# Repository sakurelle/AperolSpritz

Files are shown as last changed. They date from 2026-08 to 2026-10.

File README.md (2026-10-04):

# AperolSpritz — измеритель длины игл на ESP32-C3

AperolSpritz — автоматический измеритель длины игл на базе ESP32-C3 и шагового двигателя с драйвером TMC2209.

Устройство поддерживает ручное и автоматическое измерение, ручную и автоматическую калибровку, Web UI, сохранение настроек в NVS, сервисную калибровку перемещения в миллиметрах, аварийный STOP, световую и звуковую индикацию.

---

# 1. Как пользоваться

## 1.1. Перед первым использованием

Перед началом работы:

1. Убедитесь, что каретка свободно перемещается и механически не упирается в край хода.
2. Убедитесь, что `CONTACT` в исходном положении разомкнут.
3. Убедитесь, что кнопка `STOP` не нажата.
4. Проверьте работу оптического датчика иглы:
   - игла установлена → `NEEDLE = LOW`;
   - игла отсутствует → `NEEDLE = HIGH`.
5. Подключитесь к Web UI.
6. Проверьте настройки оператора:
   - номинальную длину;
   - допуск;
   - длину ручного калибра;
   - длину автокалибра;
   - расстояние отъезда;
   - направление движения (`Инвертировать DIR`).
7. При необходимости сначала откалибруйте масштаб перемещения в сервисном разделе.
8. Выполните калибровку устройства.

> После изменения `mm_per_step`, длины ручного/автоматического калибра или направления DIR текущая метрологическая калибровка становится недействительной. После таких изменений нужно выполнить калибровку заново.

---

# 2. Web-интерфейс

После подключения ESP32-C3 к сети откройте в браузере (IP-адрес указан на шаговом двигателе):

```text
http://<IP-адрес устройства>/
```

Интерфейс показывает:

- последнее измерение;
- отклонение от номинала;
- номинальную длину;
- допуск;
- цветовую оценку результата;
- состояние иглы;
- состояние CONTACT;
- состояние STOP;
- текущую ошибку;
- режим Wi-Fi и IP;
- текущую фазу FSM;
- состояние автоматического режима;
- тип и опорную длину последней калибровки;
- количество измерений после калибровки;
- сервисную калибровку перемещения.

### Цвет результата

В Web UI используется следующая индикация:

- **зелёный** — результат находится в допуске и не ближе 80% допуска к его границе;
- **жёлтый** — результат ещё в допуске, но отклонение достигло не менее 80% допуска;
- **красный** — результат вышел за допуск;
- **серый** — измерения ещё не было.

---

# 3. Ручной режим

## 3.1. Ручная калибровка

Ручная калибровка задаёт точку отсчёта для последующих измерений.

Перед калибровкой:

- `STOP` должен быть неактивен;
- `CONTACT` должен быть свободен;
- автоматический режим должен быть выключен;
- в настройках должна быть указана фактическая длина ручного калибра.

Калибровку можно запустить:

- кнопкой `CALIBRATE`;
- кнопкой **Калибровать** в Web UI.

Оптический датчик `NEEDLE` при ручной калибровке не используется.

Последовательность:

```text
быстрый подход
    ↓
CONTACT
    ↓
отъезд
    ↓
медленный точный подход
    ↓
CONTACT
    ↓
финальный отъезд
    ↓
готово
```

В качестве калибровочной координаты сохраняется только точка второго, медленного касания.

После успешной калибровки устройство запоминает:

- координату точного CONTACT;
- длину использованного калибра;
- тип калибровки `MANUAL`.

---

## 3.2. Ручное измерение

Перед измерением должны выполняться условия:

- устройство откалибровано;
- игла обнаружена оптическим датчиком;
- `CONTACT` в исходном положении свободен;
- `STOP` неактивен.

Измерение можно запустить:

- кнопкой `MEASURE`;
- кнопкой **Измерить** в Web UI.

Алгоритм такой же двухпроходный:

```text
быстрый подход
    ↓
CONTACT
    ↓
отъезд
    ↓
медленный точный подход
    ↓
CONTACT
    ↓
финальный отъезд
    ↓
результат
```

Итоговая длина определяется по координате второго касания.

После точного касания в `MEASURE_FINE` результат уже зафиксирован, поэтому во время финального отъезда иглу можно снимать.

---

# 4. Автоматический режим

Автоматический режим предназначен для циклической работы без запуска каждого измерения вручную.

Включается кнопкой:

```text
Авто: ВКЛ
```

в Web UI.

Автоматический цикл:

```text
ожидание иглы
    ↓
игла установлена
    ↓
автоматическое измерение
    ↓
ожидание снятия иглы
    ↓
игла снята
    ↓
автокалибровка
    ↓
возврат каретки в загрузочную позицию
    ↓
ожидание освобождения оптического датчика
    ↓
ожидание следующей иглы
```

В автоматическом режиме оптический датчик используется для определения установки и снятия иглы.

Во время самой автокалибровки и возврата каретки ложные перекрытия оптического датчика не должны запускать новое измерение. Новая игла принимается только после того, как датчик сначала устойчиво подтвердил свободное состояние.

Автоматический режим выключается при:

- STOP;
- ошибке;
- ручной команде остановки AUTO.

После перезагрузки автоматический режим не считается включённым.

---

# 5. Световая и звуковая индикация

## Буззер (Динамик)

Текущая прошивка использует активный буззер на `GPIO8`.

Сигналы:

- короткий писк — началось измерение;
- короткий писк — началась калибровка;
- более длинный писк — операция успешно завершена и устройство снова перешло в ожидание;
- три коротких прерывистых сигнала — возникла ошибка.

Сервисное перемещение не использует обычные сигналы измерения/калибровки.

Параметры звука находятся в:

```text
main/config/indicator_config.hpp
```

Основные параметры:

```cpp
BUZZER_START_MS
BUZZER_SUCCESS_MS
BUZZER_ERROR_ON_MS
BUZZER_ERROR_OFF_MS
BUZZER_ERROR_COUNT
BUZZER_INVERTED
```

## Светодиод

Статусный светодиод подключён к `GPIO9`.

Логика:

| Состояние | LED |
|---|---|
| Ожидание | выключен |
| Измерение | горит |
| Калибровка | горит |
| Возврат / JOG / сервисное движение | горит |
| ERROR | мигает |
| STOP | выключен |

В текущей конфигурации:

```cpp
STATUS_LED_INVERTED = true;
```

То есть логическое включение LED соответствует низкому уровню на GPIO9.

---

# 6. STOP и ошибки

## STOP

`STOP` имеет максимальный приоритет.

При его срабатывании:

- STEP немедленно прекращается;
- TMC2209 отключается через `EN`;
- автоматический режим выключается;
- текущий звук прекращается;
- FSM переходит в `STOPPED`.

После физического освобождения кнопки STOP нужно выполнить:

```text
Сброс STOP
```

в Web UI.

## Ошибки

При ошибке:

- двигатель останавливается;
- автоматический режим выключается;
- статусный LED начинает мигать;
- буззер один раз воспроизводит прерывистый аварийный сигнал;
- устройство остаётся в `ERROR`.

После устранения причины нажмите:

```text
Сброс ошибки
```

Основные ошибки:

| Ошибка | Значение |
|---|---|
| `NEEDLE_NOT_FOUND` | игла не обнаружена или исчезла во время измерения |
| `CONTACT_ALREADY_ACTIVE` | CONTACT уже замкнут до начала операции |
| `CONTACT_RELEASE_TIMEOUT` | после отъезда CONTACT не освободился |
| `MEASUREMENT_TIMEOUT` | превышено максимальное время измерения |
| `CALIBRATION_TIMEOUT` | превышено максимальное время калибровки |
| `MAX_STEPS_REACHED` | достигнут лимит перемещения |
| `NOT_CALIBRATED` | попытка измерения без действующей калибровки |
| `STOP_ACTIVE` | активен STOP |
| `INVALID_CONFIG` | некорректные параметры |
| `INTERNAL_ERROR` | внутренняя ошибка или остановка движения |

---

# 7. Ручной отъезд LEFT / JOG

Кнопка `LEFT` используется для ручного движения каретки от измерительного контакта.

Пока кнопка удерживается:

```text
каретка движется влево / от CONTACT
```

После отпускания движение прекращается.

JOG доступен только вне автоматического режима.

Активный CONTACT не запрещает движение от него.

---

# 8. Калибровка перемещения и mm_per_step

В нижней части Web UI расположен сервисный раздел:

```text
Калибровка перемещения
```

Он предназначен для настройки коэффициента:

```text
mm_per_step
```

то есть фактического линейного перемещения каретки на один импульс STEP.

Сервисное движение доступно только когда:

- FSM находится в `IDLE`;
- AUTO выключен;
- STOP неактивен;
- нет ошибки;
- мотор не выполняет другое движение.

Максимальная команда:

```text
±150 мм
```

Знак задаёт направление:

```text
-100 мм → влево
+100 мм → вправо
```

Если CONTACT уже активен, разрешается только движение от контакта.

## Порядок калибровки

1. Введите известное перемещение, например:

```text
-100.000 мм
```

2. Нажмите **Переместить**.
3. Измерьте реальный ход каретки.
4. Введите фактическое перемещение положительным числом, например:

```text
99.720 мм
```

5. Нажмите **Рассчитать**.

Web UI вычислит:

```text
ошибку в мм
ошибку в %
новый mm_per_step
новое количество шагов на мм
```

Используется формула:

```text
new_mm_per_step =
    old_mm_per_step × actual_distance / commanded_distance
```

6. Нажмите **Применить коэффициент**.
7. Подтвердите изменение.
8. Повторите тестовое перемещение.
9. После настройки обязательно выполните новую калибровку измерителя.

`mm_per_step` сохраняется в NVS и используется всеми преобразованиями миллиметров в шаги и обратно.

> Устройство не имеет абсолютного HOME. Перед сервисным движением оператор обязан убедиться, что каретке хватает свободного механического хода.

---

# 9. Настройки оператора

Через Web UI изменяются:

| Параметр | Назначение |
|---|---|
| Номинальная длина | размер, относительно которого рассчитывается отклонение |
| Допуск | допустимое абсолютное отклонение |
| Длина ручного калибра | известная длина при ручной калибровке |
| Длина автокалибра | известная длина встроенного автоматического калибра |
| Расстояние отъезда | ход каретки после касания CONTACT |
| Инвертировать DIR | меняет физическое направление подхода |

`mm_per_step` не редактируется в обычном блоке настроек. Он изменяется только через сервисную калибровку перемещения.

---

# 10. Как считается длина

Устройство хранит знаковую программную координату:

```text
position_steps
```

Она изменяется на каждом реально сформированном импульсе STEP.

Во время калибровки запоминается координата:

```text
calibration_contact_position_steps
```

Во время измерения:

```text
measurement_contact_position_steps
```

Расчёт основан на разности координат:

```text
L =
    calibration_reference_length_mm
    + direction_sign
    × (calibration_position - measurement_position)
    × mm_per_step
```

Направление автоматически учитывает параметр `measure_dir_inverted`.

`position_steps` является относительной программной координатой.

Она остаётся корректной только пока:

- двигатель не пропускает шаги;
- каретка не перемещается вручную при отключённом приводе;
- механика не проскальзывает.

Абсолютного HOME-датчика в текущей конструкции нет.

---

# 11. Алгоритм CONTACT

CONTACT — отдельный измерительный вход.

Логика:

```text
HIGH = свободен
LOW  = контакт замкнут
```

При первом переходе CONTACT в LOW генерация STEP останавливается максимально быстро.

После этого контроллер подтверждает уровень с коротким debounce. Если импульс оказался дребезгом и CONTACT снова стал HIGH, текущее движение продолжается без сброса программной координаты.

В итоговую калибровку и измерение используется только точка второго, медленного касания.

---

# 12. Подключение электроники

Текущая прошивка рассчитана на ESP32-C3 и драйвер TMC2209 в режиме STEP/DIR/EN.

UART-интерфейс TMC2209 прошивкой не используется.

## GPIO

| GPIO | Сигнал | Тип | Логика |
|---:|---|---|---|
| 0 | `STOP` | вход | LOW — аварийная остановка |
| 1 | `LEFT` | вход | LOW — ручной отъезд |
| 2 | `CALIBRATE` | вход | LOW — ручная калибровка |
| 3 | `CONTACT` | вход | LOW — контакт замкнут |
| 4 | `NEEDLE` | вход | LOW — игла есть, HIGH — иглы нет |
| 5 | `DIR` | выход | направление TMC2209 |
| 6 | `STEP` | выход | импульсы TMC2209 |
| 7 | `EN` | выход | LOW — драйвер включён |
| 8 | `BUZZER` | выход | звуковая индикация |
| 9 | `STATUS_LED` | выход | статусный LED, по умолчанию active-low |
| 10 | `MEASURE` | вход | LOW — ручное измерение |

### Кнопки

`STOP`, `LEFT`, `CALIBRATE`, `MEASURE` и `CONTACT` настроены как active-low входы с внутренней подтяжкой вверх.

Для обычной кнопки:

```text
GPIO ─── кнопка ─── GND
```

### Оптический датчик NEEDLE

GPIO4 не использует внутреннюю подтяжку.

Датчик должен сам формировать цифровой уровень:

```text
датчик OUT → GPIO4
датчик GND → общий GND
```

Логика текущей прошивки:

```text
LOW  = игла обнаружена
HIGH = игла отсутствует
```

Выход датчика должен быть совместим с логическими уровнями ESP32-C3.

### CONTACT

CONTACT электрически независим от оптического датчика.

Контакт должен замыкать GPIO3 на GND:

```text
GPIO3 ─── CONTACT ─── GND
```

### TMC2209

Минимальные управляющие сигналы:

```text
GPIO5 → DIR
GPIO6 → STEP
GPIO7 → EN
GND   → GND драйвера
```

`EN` активен низким уровнем.

Питание двигателя, ток драйвера и микрошаг должны быть настроены в соответствии с конкретным двигателем, драйвером и механикой. Эти параметры прошивка не конфигурирует.

### Буззер

Текущая прошивка:

```text
GPIO8 → BUZZER
```

`BUZZER_INVERTED = false`.

Если используется активный буззер в текущей прототипной схеме:

```text
GPIO8 → (+) buzzer
GND   → (-) buzzer
```

Если конкретный буззер требует ток выше допустимого для GPIO, его нужно подключать через транзисторный ключ.

### Статусный LED

Текущая прошивка использует active-low LED:

```text
3.3 V
  │
резистор
  │
 LED
  │
GPIO9
```

По умолчанию:

```text
GPIO9 LOW  → LED ON
GPIO9 HIGH → LED OFF
```

---

# 13. Важное замечание по GPIO2, GPIO8 и GPIO9

GPIO2, GPIO8 и GPIO9 у ESP32-C3 являются strapping-пинами и считываются во время reset.

В текущей распиновке на них находятся:

```text
GPIO2 → CALIBRATE
GPIO8 → BUZZER
GPIO9 → STATUS_LED
```

Поэтому внешняя схема не должна принудительно формировать неправильные уровни на этих выводах во время загрузки.

В частности:

- не удерживайте `CALIBRATE` нажатой при включении/сбросе;
- не допускайте сильной внешней подтяжки GPIO9 к GND во время reset;
- не устанавливайте большую ёмкость на GPIO9;
- при проблемах с загрузкой сначала отключите внешние цепи GPIO2/GPIO8/GPIO9 и проверьте старт ESP32-C3.

---

# 14. Wi-Fi

Прошивка поддерживает:

- WPA2-PSK;
- WPA2-Enterprise / PEAP;
- автоматический fallback Access Point.

## Настройка STA

Скопируйте:

```text
secrets.example.txt
```

в:

```text
secrets.txt
```

и укажите реальные параметры сети.

> `secrets.txt` содержит пароль. Не добавляйте этот файл в Git!!!

### WPA2-PSK

```text
WIFI_AUTH=psk
WIFI_SSID=YOUR_SSID
WIFI_PASSWORD=YOUR_PASSWORD
```

### WPA2-Enterprise / PEAP

```text
WIFI_AUTH=enterprise
WIFI_SSID=YOUR_SSID
WIFI_IDENTITY=YOUR_IDENTITY
WIFI_USERNAME=YOUR_USERNAME
WIFI_PASSWORD=YOUR_PASSWORD
```

Во время сборки `secrets.txt` преобразуется CMake в заголовочный файл внутри build directory.

Пароль не отдаётся через Web UI или REST API.

## Fallback AP

Если credentials отсутствуют, некорректны или устройство не подключилось к STA за время ожидания, запускается точка доступа:

```text
SSID:     NeedleMeter
Password: NeedleMeter2026
IP:       192.168.4.1
```

После подключения откройте:

```text
http://192.168.4.1/
```

Если STA-соединение было установлено, но затем потеряно, прошивка пытается переподключиться.

Физические кнопки и измерительная FSM не зависят от доступности Wi-Fi.

---

# 15. Технические параметры движения

Основные compile-time параметры находятся в:

```text
main/config/motion_config.hpp
```

Текущие значения:

| Параметр | Значение |
|---|---:|
| Coarse speed | 1500 шаг/с |
| Fine speed | 500 шаг/с |
| Retract speed | 1500 шаг/с |
| Auto load speed | 4000 шаг/с |
| JOG speed | 4000 шаг/с |
| Service move speed | 4000 шаг/с |
| Acceleration | 4000 шаг/с² |
| Max retract | 20 мм |
| Max measurement move | 75 мм |
| Max calibration move | 75 мм |
| Max auto load move | 30 мм |
| Max service move | 150 мм |
| CONTACT debounce | 3 мс |
| NEEDLE debounce AUTO | 100 мс |
| STEP high | 4 мкс |
| AUTO load position | 182 мм |

Начальное значение масштаба:

```text
DEFAULT_MM_PER_STEP = 0.0003127
```

Рабочий `mm_per_step` хранится в `DeviceConfig` и NVS.

---

# 16. Сборка прошивки

Проект использует:

```text
PlatformIO
ESP-IDF
ESP32-C3 DevKitM-1
```

Конфигурация находится в:

```text
platformio.ini
```

Сборка:

```powershell
pio run
```

Прошивка:

```powershell
pio run -t upload
```

Монитор:

```powershell
pio device monitor
```

Скорость монитора:

```text
115200 baud
```

Консоль ESP-IDF настроена через USB Serial/JTAG.

---

# 17. REST API

Web UI использует тот же REST API.

| Метод | Endpoint | Назначение |
|---|---|---|
| GET | `/api/status` | текущее состояние |
| GET | `/api/config` | текущая конфигурация |
| POST | `/api/config` | сохранить настройки оператора |
| POST | `/api/measure` | начать измерение |
| POST | `/api/calibrate` | начать ручную калибровку |
| POST | `/api/auto/start` | включить AUTO |
| POST | `/api/auto/stop` | выключить AUTO |
| POST | `/api/stop` | программный STOP |
| POST | `/api/reset-stop` | сбросить STOP |
| POST | `/api/reset-error` | сбросить ERROR |
| POST | `/api/factory-reset` | сбросить NVS к значениям по умолчанию |
| POST | `/api/service-move` | сервисное перемещение в мм |
| POST | `/api/service/mm-per-step` | сохранить новый коэффициент mm/step |

Пример сервисного перемещения:

```json
{
  "distance_mm": -100.0
}
```

---

# 18. Хранение конфигурации

Настройки и статистика сохраняются в NVS namespace:

```text
needle_meter
```

В NVS сохраняются, в частности:

- настройки оператора;
- `mm_per_step`;
- последняя действующая калибровка;
- тип калибровки;
- координата калибровочного CONTACT;
- последнее измерение;
- счётчики измерений и калибровок.

Текущая версия структуры конфигурации:

```text
CONFIG_VERSION = 5
```

При обновлении с версии 4 настройки оператора мигрируют в v5, а новый `mm_per_step` получает значение по умолчанию.

---

# 19. Структура проекта

```text
AperolSpritz/
├── hardware/                     # аппаратная/механическая часть проекта
├── main/
│   ├── app_main.cpp              # запуск подсистем
│   ├── config/
│   │   ├── pins.hpp              # назначение GPIO
│   │   ├── motion_config.hpp     # скорости и ограничения движения
│   │   ├── indicator_config.hpp
│   │   ├── device_config.*
│   │   └── config_storage.*
│   ├── gpio/                     # кнопки и датчики
│   ├── motor/                    # STEP/DIR/EN и GPTimer
│   ├── indication/               # buzzer + status LED
│   ├── measurement/              # FSM измерения и калибровки
│   ├── wifi/                     # STA / WPA2 Enterprise / fallback AP
│   └── web/                      # Web UI и REST API
├── platformio.ini
├── sdkconfig.defaults
├── secrets.example.txt
└── README.md
```

---

# 20. Общая архитектура

```text
Кнопки / датчики
       │
       ▼
   GpioManager
       │
       ▼
MeasurementController
       │
       ├────────► IndicatorManager
       │             ├─ buzzer
       │             └─ status LED
       │
       ▼
  StepperMotor
       │
       ▼
STEP / DIR / EN
       │
       ▼
    TMC2209
```

Web UI работает через REST API:

```text
Browser
   │
   ▼
WebServer
   │
   ▼
очередь команд
   │
   ▼
MeasurementController
```

HTTP handler не управляет мотором напрямую.

STEP формируется аппаратным GPTimer, а логика измерения выполняется конечным автоматом в отдельной FreeRTOS-задаче.

---

# 21. Типичный порядок настройки нового устройства

```text
Сборка механики и электроники
        ↓
проверка направления движения
        ↓
проверка STOP / CONTACT / NEEDLE
        ↓
настройка Wi-Fi
        ↓
сервисное перемещение ±100 мм
        ↓
коррекция mm_per_step
        ↓
повторная проверка перемещения
        ↓
ввод точной длины калибра
        ↓
калибровка
        ↓
контрольные измерения известных игл
        ↓
работа в ручном или автоматическом режиме
```

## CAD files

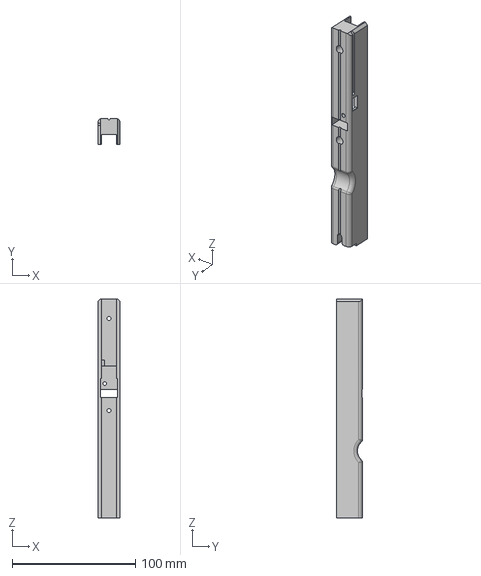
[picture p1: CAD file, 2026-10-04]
hardware/step/NeedleBase.stp
18.0 x 21.0 x 178.0 mm

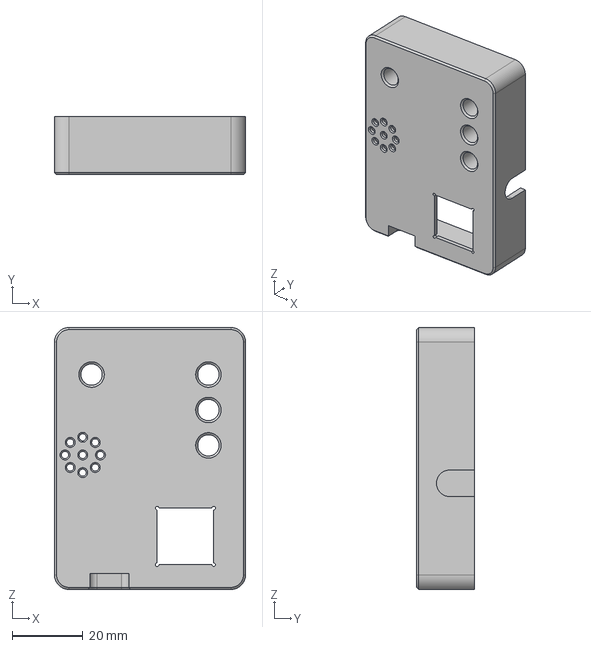
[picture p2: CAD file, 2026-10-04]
hardware/step/ControlHolderUp.stp
54.0 x 16.4 x 74.0 mm

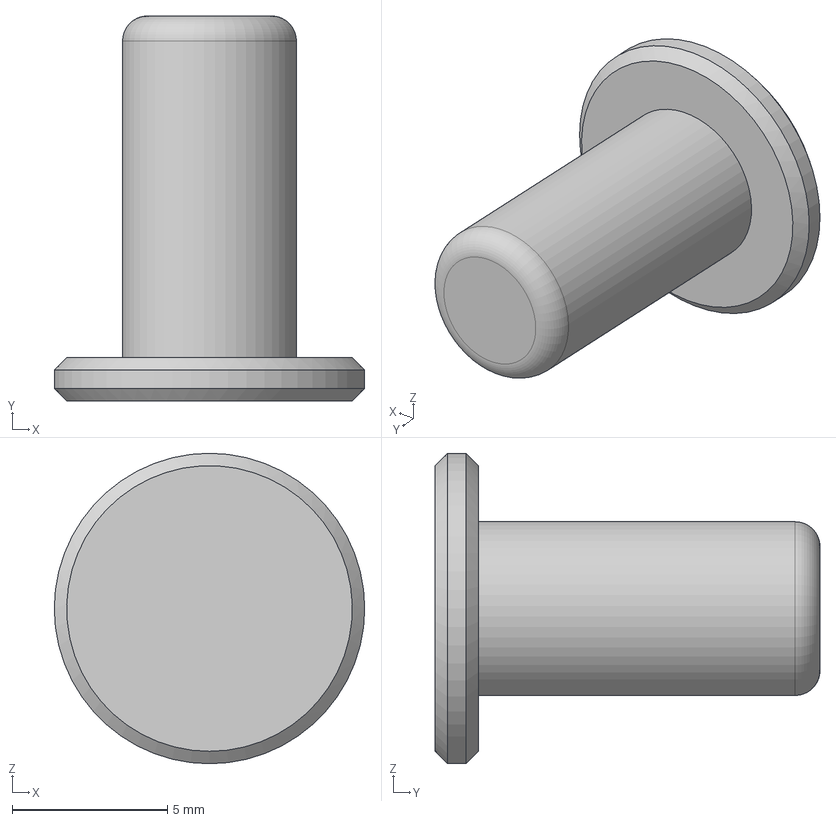
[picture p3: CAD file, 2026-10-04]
hardware/step/Button.stp
10.0 x 12.4 x 10.0 mm

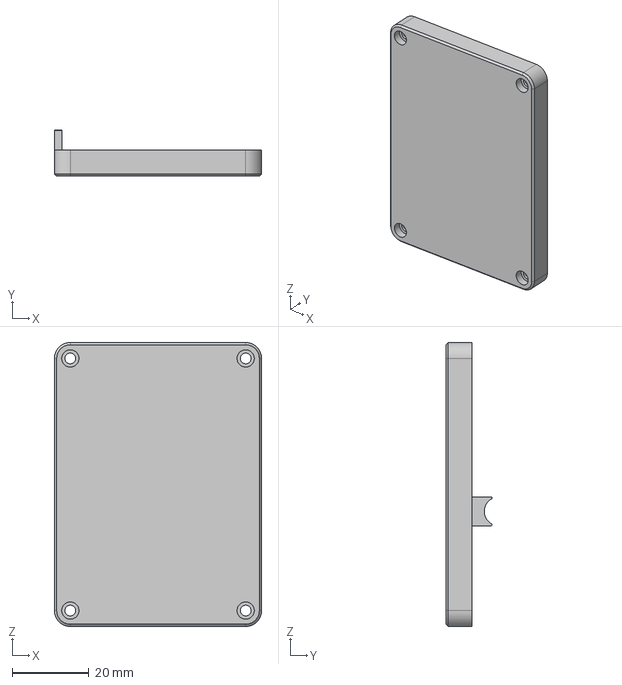
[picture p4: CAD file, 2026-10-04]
hardware/step/ControlHolderDown.stp
54.0 x 12.1 x 74.0 mm

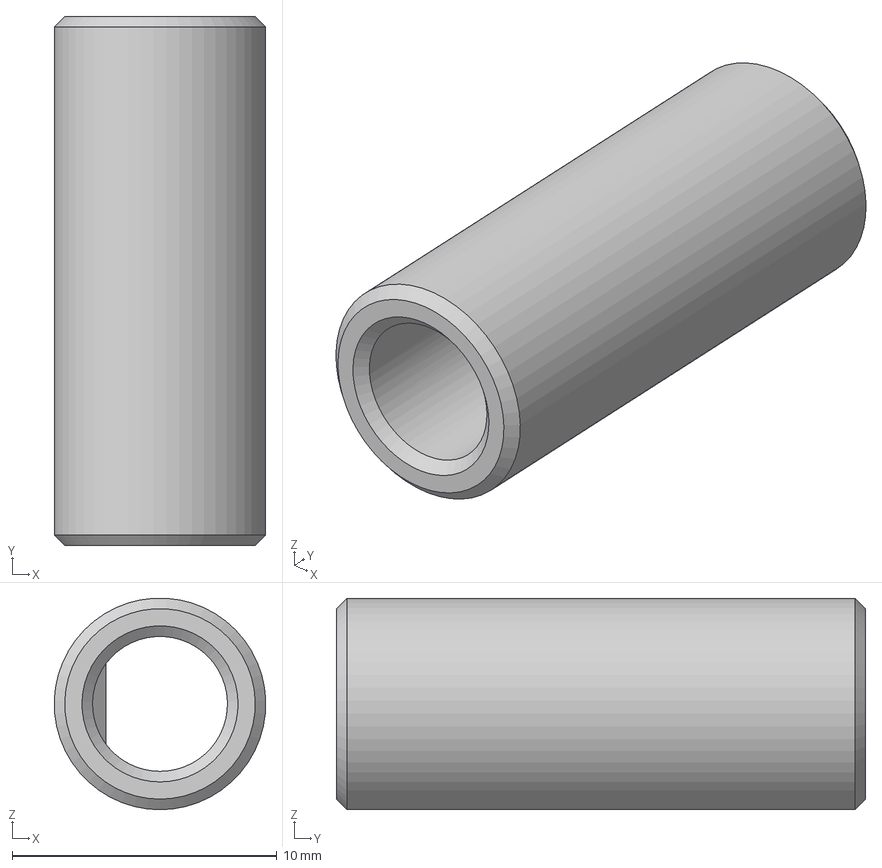
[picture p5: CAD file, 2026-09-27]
hardware/step/MotorWall.stp
8.00 x 20.0 x 7.99 mm

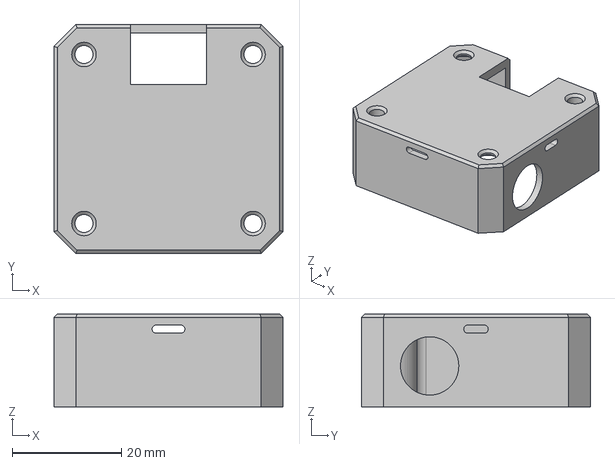
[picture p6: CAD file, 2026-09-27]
hardware/step/MotorWireBox.stp
42.0 x 42.0 x 17.0 mm

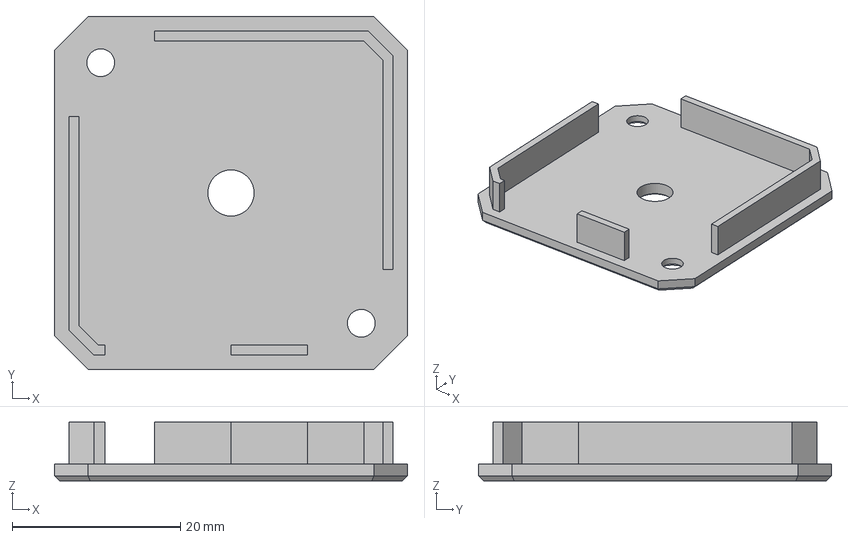
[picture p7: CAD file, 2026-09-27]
hardware/step/MotorWireRoof.stp
42.0 x 42.0 x 7.00 mm

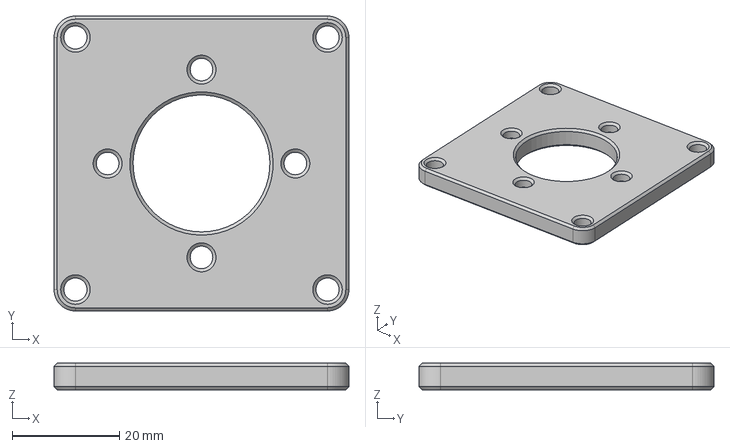
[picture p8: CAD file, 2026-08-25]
hardware/step/MotorBase.stp
55.0 x 55.0 x 5.00 mm

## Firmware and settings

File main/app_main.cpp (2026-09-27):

#include "driver/gpio.h"
#include "esp_log.h"
#include "config/pins.hpp"
#include "config/config_storage.hpp"
#include "gpio/gpio_manager.hpp"
#include "indication/indicator_manager.hpp"
#include "motor/stepper_motor.hpp"
#include "measurement/measurement_controller.hpp"
#include "wifi/wifi_manager.hpp"
#include "web/web_server.hpp"

static const char *TAG = "app";
// app_main returns after startup, so application services must not be stack objects.
static ConfigStorage storage;
static StepperMotor motor;
static GpioManager gpio;
static IndicatorManager indicator;
static MeasurementController controller;
static WifiManager wifi;
static WebServer web;

extern "C" void app_main(void) {
    // Put the driver in a safe electrical state before NVS, Wi-Fi, or any task can run.
    gpio_config_t safety{};
    safety.pin_bit_mask = (1ULL << STEP_PIN) | (1ULL << DIR_PIN) | (1ULL << EN_PIN);
    safety.mode = GPIO_MODE_OUTPUT;
    ESP_ERROR_CHECK(gpio_config(&safety));
    ESP_ERROR_CHECK(gpio_set_level(STEP_PIN, 0));
    ESP_ERROR_CHECK(gpio_set_level(DIR_PIN, 0));
    ESP_ERROR_CHECK(gpio_set_level(EN_PIN, 1)); // TMC2209 EN is active LOW
    if (indicator.init() != ESP_OK) { ESP_LOGE(TAG, "Indicator initialization failed"); return; }

    if (storage.init() != ESP_OK) { ESP_LOGE(TAG, "NVS initialization failed; motor remains disabled"); return; }
    DeviceConfig config; DeviceStats stats; bool defaults = false;
    if (storage.load(config, stats, defaults) != ESP_OK || !validate_config(config)) { ESP_LOGE(TAG, "Invalid NVS configuration; motor remains disabled"); return; }
    if (defaults) { ESP_LOGW(TAG, "Using factory defaults"); storage.save_config(config); storage.save_stats(stats); }

    if (motor.init() != ESP_OK) { ESP_LOGE(TAG, "Motor initialization failed"); return; }
    if (controller.init(&motor, &gpio, &storage, &indicator, config, stats) != ESP_OK) { ESP_LOGE(TAG, "GPIO/controller initialization failed"); motor.stop(); return; }
    if (controller.start_task() != ESP_OK) { ESP_LOGE(TAG, "Controller task initialization failed"); motor.stop(); return; }

    if (wifi.start() != ESP_OK) ESP_LOGE(TAG, "Wi-Fi unavailable; physical controls remain active");
    if (web.start(&controller, &wifi) != ESP_OK) ESP_LOGE(TAG, "HTTP server unavailable; physical controls remain active");
}

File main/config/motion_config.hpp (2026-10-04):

#pragma once

#include <cmath>
#include <limits>
#include <stdint.h>

// Machine-specific motion limits and speeds. The actual carriage scale lives
// in DeviceConfig so it can be calibrated and persisted in NVS.
namespace motion_config {
constexpr double DEFAULT_MM_PER_STEP = 0.0003127;
constexpr double MIN_MM_PER_STEP = 0.00001;
constexpr double MAX_MM_PER_STEP = 0.01;
constexpr uint32_t COARSE_SPEED_STEPS_S = 1500;
constexpr uint32_t FINE_SPEED_STEPS_S = 500;
constexpr uint32_t RETRACT_SPEED_STEPS_S = 1500;
constexpr uint32_t AUTO_LOAD_SPEED_STEPS_S = 4000;
constexpr uint32_t JOG_SPEED_STEPS_S = 4000;
constexpr uint32_t SERVICE_MOVE_SPEED_STEPS_S = 4000;
constexpr uint32_t ACCELERATION_STEPS_S2 = 4000;

constexpr double MAX_RETRACT_MM = 20.0;
constexpr double MAX_MEASUREMENT_MM = 75.0;
constexpr double MAX_CALIBRATION_MM = 75.0;
constexpr double MAX_AUTO_LOAD_MM = 30.0;
constexpr double MAX_SERVICE_MOVE_MM = 150.0;

// Returns zero for invalid, unrepresentable, or sub-step distances. All
// runtime mm/step conversions must go through these helpers.
inline uint32_t mm_to_steps(double mm, double mm_per_step) {
    const double distance = std::fabs(mm);
    if (!std::isfinite(distance) || !std::isfinite(mm_per_step) || mm_per_step <= 0.0) return 0;
    const double raw_steps = distance / mm_per_step;
    if (!std::isfinite(raw_steps) || raw_steps < 0.5 || raw_steps > static_cast<double>(std::numeric_limits<uint32_t>::max())) return 0;
    return static_cast<uint32_t>(std::llround(raw_steps));
}

inline double steps_to_mm(int64_t steps, double mm_per_step) {
    return std::isfinite(mm_per_step) && mm_per_step > 0.0 ? static_cast<double>(steps) * mm_per_step : 0.0;
}

constexpr uint32_t MEASUREMENT_TIMEOUT_MS = 180000;
constexpr uint32_t CALIBRATION_TIMEOUT_MS = 240000;
constexpr uint32_t CONTACT_RELEASE_TIMEOUT_MS = 10000;
constexpr uint32_t CONTACT_DEBOUNCE_MS = 3;
constexpr uint32_t MOTION_STALL_TIMEOUT_MS = 1000;
constexpr uint32_t STEP_HIGH_US = 4;
constexpr uint32_t NEEDLE_DEBOUNCE_MS = 100;
constexpr double AUTO_LOAD_POSITION_MM = 182.0;
} // namespace motion_config

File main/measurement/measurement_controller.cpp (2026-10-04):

#include "measurement/measurement_controller.hpp"

#include "config/config_storage.hpp"
#include "config/motion_config.hpp"
#include "esp_log.h"
#include "esp_timer.h"
#include "indication/indicator_manager.hpp"
#include "motor/stepper_motor.hpp"

#include <cmath>
#include <cstring>

namespace {
constexpr char TAG[] = "measurement";
constexpr uint32_t OPTICAL_NEEDLE_LOSS_DEBOUNCE_MS = 5;
uint32_t now_ms() { return static_cast<uint32_t>(esp_timer_get_time() / 1000); }
constexpr double approach_direction_sign(bool measure_dir_inverted) { return measure_dir_inverted ? 1.0 : -1.0; }
constexpr double length_from_positions(double reference_length_mm, int64_t calibration_position_steps, int64_t measurement_position_steps, bool measure_dir_inverted, double mm_per_step) {
    return reference_length_mm + approach_direction_sign(measure_dir_inverted) * static_cast<double>(calibration_position_steps - measurement_position_steps) * mm_per_step;
}
static_assert(length_from_positions(172.0, 100000, 90000, true, 0.000242) > 172.0, "Positive approach must make a longer object longer");
static_assert(length_from_positions(172.0, -100000, -90000, false, 0.000242) > 172.0, "Negative approach must make a longer object longer");
}

const char *state_name(DeviceState state) {
    switch (state) {
    case DeviceState::IDLE: return "IDLE"; case DeviceState::MEASURE_FAST: return "MEASURE_FAST"; case DeviceState::MEASURE_RETRACT: return "MEASURE_RETRACT";
    case DeviceState::MEASURE_FINE: return "MEASURE_FINE"; case DeviceState::MEASURE_FINAL_RETRACT: return "MEASURE_FINAL_RETRACT";
    case DeviceState::CALIBRATE_FAST: return "CALIBRATE_FAST"; case DeviceState::CALIBRATE_RETRACT: return "CALIBRATE_RETRACT";
    case DeviceState::CALIBRATE_FINE: return "CALIBRATE_FINE"; case DeviceState::CALIBRATE_FINAL_RETRACT: return "CALIBRATE_FINAL_RETRACT";
    case DeviceState::AUTO_WAIT_SENSOR_CLEAR: return "AUTO_WAIT_SENSOR_CLEAR"; case DeviceState::AUTO_WAIT_NEEDLE: return "AUTO_WAIT_NEEDLE"; case DeviceState::AUTO_WAIT_REMOVE: return "AUTO_WAIT_REMOVE"; case DeviceState::AUTO_MOVE_TO_LOAD: return "AUTO_MOVE_TO_LOAD";
    case DeviceState::MANUAL_LEFT: return "MANUAL_LEFT"; case DeviceState::SERVICE_MOVE: return "SERVICE_MOVE"; case DeviceState::FINISHED: return "FINISHED"; case DeviceState::STOPPED: return "STOPPED"; case DeviceState::ERROR: return "ERROR";
    } return "ERROR";
}
const char *error_name(ErrorCode error) {
    switch (error) {
    case ErrorCode::None: return "NONE"; case ErrorCode::NeedleNotFound: return "NEEDLE_NOT_FOUND"; case ErrorCode::ContactAlreadyActive: return "CONTACT_ALREADY_ACTIVE";
    case ErrorCode::ContactReleaseTimeout: return "CONTACT_RELEASE_TIMEOUT"; case ErrorCode::MeasurementTimeout: return "MEASUREMENT_TIMEOUT"; case ErrorCode::CalibrationTimeout: return "CALIBRATION_TIMEOUT";
    case ErrorCode::MaxStepsReached: return "MAX_STEPS_REACHED"; case ErrorCode::NotCalibrated: return "NOT_CALIBRATED"; case ErrorCode::StopActive: return "STOP_ACTIVE";
    case ErrorCode::InvalidConfig: return "INVALID_CONFIG"; case ErrorCode::InternalError: return "INTERNAL_ERROR";
    } return "INTERNAL_ERROR";
}

esp_err_t MeasurementController::init(StepperMotor *motor, GpioManager *gpio, ConfigStorage *storage, IndicatorManager *indicator, DeviceConfig config, DeviceStats stats) {
    if (!motor || !gpio || !storage || !indicator) return ESP_ERR_INVALID_ARG;
    motor_ = motor; gpio_ = gpio; storage_ = storage; indicator_ = indicator; config_ = config; stats_ = stats;
    gpio_queue_ = xQueueCreate(16, sizeof(GpioEvent)); command_queue_ = xQueueCreate(8, sizeof(ControllerCommand)); mutex_ = xSemaphoreCreateMutex();
    if (!gpio_queue_ || !command_queue_ || !mutex_) return ESP_ERR_NO_MEM;
    return gpio_->init(gpio_queue_, motor_);
}
esp_err_t MeasurementController::start_task() { if (!gpio_queue_ || !command_queue_ || !mutex_ || !motor_ || !gpio_ || !storage_) return ESP_ERR_INVALID_STATE; return xTaskCreate(task_entry, "measurement", 4096, this, 10, nullptr) == pdPASS ? ESP_OK : ESP_ERR_NO_MEM; }
void MeasurementController::task_entry(void *context) { static_cast<MeasurementController *>(context)->run(); }
bool MeasurementController::enqueue(CommandType type) { const ControllerCommand c{type}; return command_queue_ && xQueueSend(command_queue_, &c, 0) == pdTRUE; }

bool MeasurementController::enqueue_service_move(double distance_mm, const char **reason) {
    if (!mutex_ || !command_queue_) { if (reason) *reason = "Controller unavailable"; return false; }
    if (xSemaphoreTake(mutex_, pdMS_TO_TICKS(50)) != pdTRUE) { if (reason) *reason = "Controller busy"; return false; }
    const bool allowed = service_move_allowed(distance_mm, reason);
    const bool queue_empty = uxQueueMessagesWaiting(command_queue_) == 0;
    if (allowed && !queue_empty && reason) *reason = "Controller command pending";
    const ControllerCommand command{CommandType::ServiceMove, distance_mm};
    const bool queued = allowed && queue_empty && xQueueSend(command_queue_, &command, 0) == pdTRUE;
    if (allowed && queue_empty && !queued && reason) *reason = "Command queue full";
    xSemaphoreGive(mutex_);
    return queued;
}

bool MeasurementController::update_config(const DeviceConfig &config, const char **reason) {
    if (!validate_config(config, reason) || !mutex_) return false;
    if (xSemaphoreTake(mutex_, pdMS_TO_TICKS(50)) != pdTRUE) { if (reason) *reason = "Controller busy"; return false; }
    if (state_ != DeviceState::IDLE) { xSemaphoreGive(mutex_); if (reason) *reason = "Settings can be changed only in IDLE"; return false; }
    const double old_mm_per_step = config_.mm_per_step;
    const bool mm_per_step_changed = std::fabs(config.mm_per_step - old_mm_per_step) > 1e-12;
    const bool invalidate = std::fabs(config.calibration_length_mm - config_.calibration_length_mm) > 1e-12 || std::fabs(config.auto_calibration_length_mm - config_.auto_calibration_length_mm) > 1e-12 || config.measure_dir_inverted != config_.measure_dir_inverted || mm_per_step_changed;
    DeviceStats updated_stats = stats_;
    if (invalidate) { updated_stats.calibration_valid = false; updated_stats.calibration_source = CalibrationSource::None; updated_stats.calibration_reference_length_mm = 0; updated_stats.measurements_since_calibration = 0; }
    esp_err_t err = invalidate ? storage_->save_stats(updated_stats) : ESP_OK;
    if (err == ESP_OK) err = storage_->save_config(config);
    if (err == ESP_OK) { config_ = config; stats_ = updated_stats; }
    else if (invalidate) stats_ = updated_stats; // A failed config write must never leave a stale calibration valid.
    if (err == ESP_OK && mm_per_step_changed) ESP_LOGI(TAG, "MM_PER_STEP updated: old=%.9f new=%.9f calibration invalidated", old_mm_per_step, config.mm_per_step);
    xSemaphoreGive(mutex_);
    if (err != ESP_OK && reason) *reason = "NVS write failed";
    return err == ESP_OK;
}
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

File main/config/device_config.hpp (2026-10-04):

#pragma once
#include "config/motion_config.hpp"

#include <stdint.h>

constexpr uint32_t CONFIG_VERSION = 5;

struct DeviceConfig {
    uint32_t config_version = CONFIG_VERSION;
    double calibration_length_mm = 41.300;
    double auto_calibration_length_mm = 170.0;
    double nominal_length_mm = 41.300;
    double tolerance_mm = 0.050;
    double retract_mm = 2.0;
    bool measure_dir_inverted = false;
    double mm_per_step = motion_config::DEFAULT_MM_PER_STEP;
};

enum class CalibrationSource : uint8_t { None, Manual, Auto };

struct DeviceStats {
    double last_measured_length = 0.0;
    double last_deviation = 0.0;
    uint32_t measurements_since_calibration = 0;
    uint32_t total_measurements = 0;
    uint32_t calibration_count = 0;
    uint32_t last_measurement_steps = 0;
    uint32_t calibration_steps = 0;
    int64_t calibration_contact_position_steps = 0;
    int64_t last_measurement_contact_position_steps = 0;
    double calibration_reference_length_mm = 0.0;
    CalibrationSource calibration_source = CalibrationSource::None;
    bool calibration_valid = false;
    char last_result[12] = "NONE";
};

DeviceConfig default_config();
bool validate_config(const DeviceConfig &config, const char **reason = nullptr);

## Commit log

2026-09-02 Fix for measure
    [NeedleBase.stp]
2026-09-03 Fix troubles with auto mod
    [measurement_controller.cpp, measurement_controller.hpp]
2026-09-08 Fix mm per step params
    [measurement_controller.cpp, motion_config.hpp]
2026-09-27 Итоговый проект
    [MotorBaseNew.stp, MotorWall.stp, MotorWireBox.stp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]
2026-09-29 Add controller case
    [Button.stp, ControlHolderDown.stp, ControlHolderUp.stp]
2026-10-04 Auto calibrate
    [Button.stp, ControlHolderDown.stp, ControlHolderUp.stp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]
2026-10-04 Добавил инструкцию
2026-10-04 Корректировка моделей
2026-10-29 Обновление десктоп версии
2026-10-29 Обновление инструкций v1.0
